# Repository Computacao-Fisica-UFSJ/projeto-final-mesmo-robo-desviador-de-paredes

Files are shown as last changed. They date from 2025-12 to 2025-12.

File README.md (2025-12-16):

# Projeto Hidroponia semi-autônomo

##### Contextualização do projeto, indicando suas aplicações e/ou motivação:

 	O intuito principal do projeto busca auxiliar cultivos de plantas no estilo hidropônico. A hidroponia é um estilo de plantação feita com as raízes da planta submersas em água nutrificada, o que o diferencia bastante do cultivo comum que geralmente requer solo geralmente fértil pra nutrição da planta pela raiz.

 	Nesse contexto, a arquitetura de hardware do projeto utiliza um microcontrolador Arduino Uno R3 como unidade central de processamento, responsável por gerenciar todas as leituras de sensores e as atuações automáticas do sistema.

Para a gestão da iluminação, o sistema emprega um sensor fotossensível LDR (Light Dependent Resistor) que monitora a incidência de luz em tempo real. Com base nesses dados, o Arduino aciona um micro servo motor acoplado mecanicamente ao eixo de um Dimmer de 2000W. Esta abordagem mecânica para o controle da intensidade da lâmpada foi adotada estrategicamente para garantir o isolamento entre o circuito de baixa tensão do microcontrolador e a alta tensão da rede elétrica, proporcionando maior segurança ao sistema enquanto assegura que a planta receba a iluminação adequada.

A aquisição de dados ambientais é realizada por sensores de alta precisão. Para a atmosfera do cultivo, utiliza-se um sensor DHT22, responsável por medir simultaneamente a temperatura e a umidade relativa do ar.

Já para o monitoramento da solução nutritiva, o projeto integra um sensor DS18B20, uma sonda digital impermeável ideal para medição submersa da temperatura da água.

Esses dados têm caráter informativo e são exibidos em uma interface homem-máquina composta por um display LCD 16x2, permitindo o acompanhamento instantâneo das condições vitais do cultivo.

Por fim, a estabilidade da nutrição é mantida por um sistema de reposição hídrica. Um sensor de nível monitora o reservatório e, ao detectar que o volume está abaixo do limiar predefinido, aciona uma bomba de água. Essa automação reabastece o sistema até que o nível se estabilize, evitando a exposição das raízes ou alterações drásticas na concentração de nutrientes.

##### Lista de materiais:

-Arduino Uno R3

-DS18B20(sensor de temperatura da água)

-fotoresistor LDR

-Micro Servo Motor 9g Sg90

-DHT22(sensor de temperatura e umidade)

-dimmer\_2000W(potenciomento da lâmpada fluorescente)

-lâmpada fluorescente

-FD10(sensor de nível de água)

AM2302-Sensor

DallasTemperature

ESP32_Thermistor

OneWire

Servo

GROVE - LCD RGB blacklight

DHT sensor library

##### Problemas encontrados no processo de montagem:

-Altas voltagem: para implementarmos a lâmpada fluorescente em nosso projeto temos o desafio de lidar com componenetes de alta voltagem (110 a 220V) o que pode causar eletrocutamento leve/moderado ao manusear componentes energizados sem o devido isolamento ou cuidado.

-O github não suporta armazenar as bibliotecas implementadas nos projetos devido ao grande número de arquivos(ele não carrega mais de 100 arquivos[pelo menos na interface de arrastar com o mouse no site, não]) o que tornou inviável salvar de forma segura as bibliotecas necessárias para o funcionamento do projeto. A alternativa que pensamos foi apenas salvar o nome das bibliotecas necessárias e, em caso de perda dessas bibliotecas de alguma forma, reinstalar uma por uma parar retomar os trabalhos.

-Tivemos muitos problemas para fazer o sensor de temperatura da água funcionar, pois não estávamos conseguindo configurar da forma correta. Devido a isso, tivemos que trocar o modelo e, após a troca, conseguimos resolver esse problema.

-Tivemos dificuldades para fazer o servo se mover na angulação correta. Além disso, foi necessário desenvolver um apoio para que o servo conseguisse aumentar e diminuir a intensidade da luz do dimmer, garantindo também a fixação adequada entre ambos.

-Outra dificuldade foi para fazer o servo funcionar junto com os outros sensores e atuadores, pois o 5V do Arduino não estava fornecendo energia suficiente para todos os componentes. Por isso, foi necessário utilizar o 5V do protoboard para garantir o funcionamento correto do sistema.

##### Diagrama da montagem:

##### Foto e vídeo do projeto:

##### Bibliotecas utilizadas:

##### 

##### Relatórios Diário

###### 

###### Dia 18/11
Querido diário, hoje buscamos pelos hardwares necessários para nosso projeto de medição de luminosidade, temperatura do ar e água, umidade, nível de água e regulador de luz e nível de água!

###### Dia 25/11
Querido diário, hoje eu e Lara criamos o código pro sensor de luminosidade, mais conhecido como LDR e pro sensor de temperatura e umidade do ar, menos conhecido como AOSONG AM2302. Também montamos ele no protoboard e depois no Arduíno, foi possível assistir a leitura tanto do nível de luminosidade do ambiente quanto o de umidade e temperatura

###### Dia 26/11
Querido diário, Lara está quebrando a cabeça pra saber como conectar o sensor de temperatura da água uma vez que ele tem uma entrada deveras estranha, ela conseguiu conectar as entradas de forma correta para lermos pelo Arduíno, eu compilei o código mas os testes foram meios decepcionantes, a temperatura da água que na teoria era pra ser ambiente teve leituras de valores menores que a água supostamente gelada, exemplo: quente:20 graus, gelada 33 graus. Enquanto eu tentava consertar de alguma forma esse empecilho, Lara achou sobre a montagem do nivelador de água mas saiu correndo com pressa pra não perder a carona e não iniciou a montar, e eu devo deixar pra tentar corrigir essa leitura depois também.

###### Dia 02/12
Querido diário, hoje ficamos por conta de fazer a prova de arduíno.

###### Dia 03/12
Querido dário, hoje implementamos separadamente os sensores de nível de água, o micro servo, o sensor de temperatura da água e o potenciômetro para controlar a intensidade da lâmpada. Inicialmente, tivemos problemas com o sensor de temperatura, que era um NTC 10k MF58, e não conseguimos fazê-lo funcionar corretamente, então resolvemos substituí-lo por um DS18B20. Após a troca, o sensor passou a funcionar da forma correta.

###### Dia 08/12
Querido diário, hoje conseguimos trocar o servo para que ele funcionasse por angulação, achamos um objeto 3d que grudamos nele para ele conseguir rodar o potenciometro do dimmer. Conseguimos também fazer o código base com todos os sensores funcionando. Além disso, conseguimos fazer o display começar a funcionar, porém com alguns problemas.

###### Dia 09/12
Querido diário, hoje conseguimos finalizar o código e apresentamos para a Milene. Conseguimos fazer a lógica do servo funcionar e também o relé da bomba funcionar. Colocamos o protótipo em uma caixa, posicionando a luz em um local adequado, próximo ao LDR, para que a lógica funcionasse corretamente. Além disso, posicionamos o dimmer e o servo de forma que o servo conseguisse girar o potenciômetro e, por último, arrumamos o display para mostrar os valores das variáveis obtidas por alguns sensores. Além disso, houve um grande avanço no README, com toda a contextualização feita, a listagem de componentes com suas respectivas imagens e um avanço no projeto em Fritzing.

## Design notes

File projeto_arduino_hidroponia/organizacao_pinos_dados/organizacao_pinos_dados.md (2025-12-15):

###Organização pinos de dados

A0->sensor de luminosidade(ldr)

A1->sensor de temperatura da agua

A2->sensor de nivel de agua

7U->sensor de umidade e temperatura do ar

6~->micro servo

SDA-display

SCL-display

2D-relé

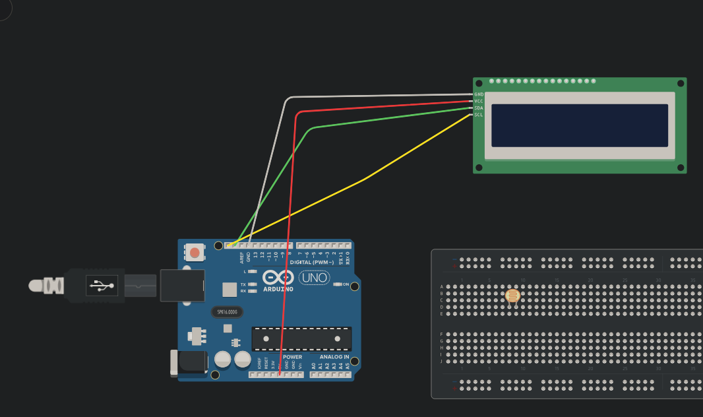
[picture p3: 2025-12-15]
projeto_arduino_hidroponia/image.png

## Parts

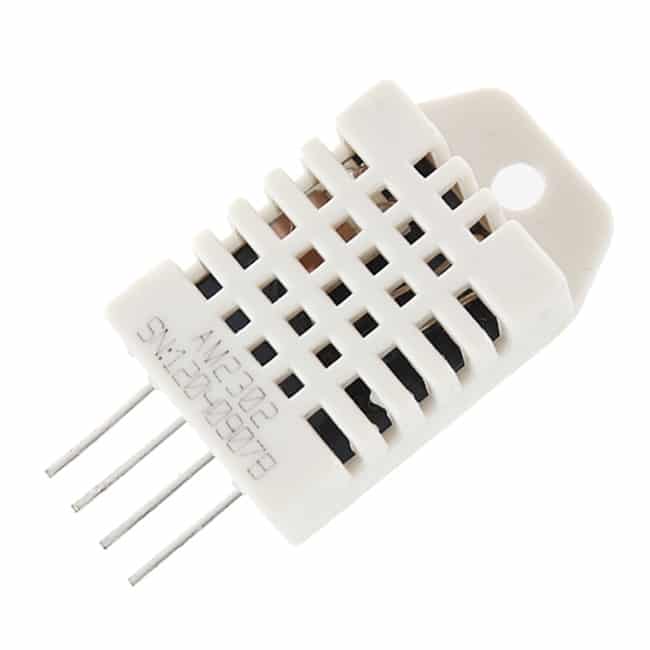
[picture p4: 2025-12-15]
imagem_componentes/DHT22(sensor_umidade_temperatura).jpg

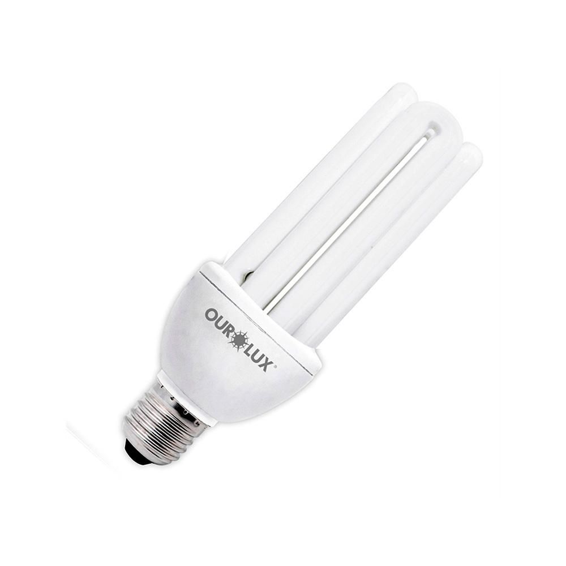
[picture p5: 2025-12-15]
imagem_componentes/lampada-eletronica-30w-x-220v-am-2700k-ourolux_1_1000.jpg

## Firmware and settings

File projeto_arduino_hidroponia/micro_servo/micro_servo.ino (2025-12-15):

// Programa: Controlando um servo motor com Arduino (servo motor arduino code) 

#include <Servo.h> // Inclui a biblioteca Servo para controlar servos

Servo meuServo; // Cria um objeto Servo para controlar o servo motor
int pos; // Declara uma variável para controlar a posição do servo motor 

void setup() {
    meuServo.attach(6); // Associa o servo motor ao pino digital 6 do Arduino
    meuServo.write(0); // Define a posição inicial do servo motor para 0 graus
}

void loop() {
    // Movimento do servo de 0 a 90 graus
    for (pos = 0; pos < 90; pos++) {
        meuServo.write(pos); // Define a posição atual do servo
        delay(15); // Aguarda 15 milissegundos antes de mover para a próxima posição
    }
    delay(1000); // Aguarda 1 segundo antes de iniciar o próximo movimento

    // Movimento do servo de 90 a 0 graus
    for (pos = 90; pos >= 0; pos--) {
        meuServo.write(pos); // Define a posição atual do servo
        delay(15); // Aguarda 15 milissegundos antes de mover para a próxima posição
    }
    delay(1000); // Aguarda 1 segundo antes de iniciar o próximo ciclo
}

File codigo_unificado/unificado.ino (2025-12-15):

#include <Wire.h> 
#include <rgb_lcd.h>
#include <Servo.h>
#include <DHT.h>
#include <OneWire.h>
#include <DallasTemperature.h>

#define DHTTYPE DHT22

// Pinos 
#define pinoRele 2
#define pinoLDR A0
#define pinoNivelAgua A2
#define pinoDHT 7
#define pinoServo 6
#define pinoTempAgua 8

//Constantes de tempo
#define intervaloTempo 2000
#define intervaloServo 2000
#define intervaloRele 4000

// Variáveis
int valorLDR = 0;
int valorNivel = 0;
float valorTempAr = 0.0;
float valorUmidade = 0.0;
float valorTempAgua = 0.0;
int intensidadeLuz = 0;
int angulo = 0;
int porcentagemNivel = 0;
int estadoRele = 0;

// variáveis de tempo
unsigned long tempoAtual;
unsigned long tempoAnterior = 0;
unsigned long tempoAnteriorServo = 0;
unsigned long tempoAnteriorRele = 0;

//Objetos
Servo servo;
rgb_lcd LCD;
DHT dht(pinoDHT, DHTTYPE);
OneWire sensorTemp(pinoTempAgua);
DallasTemperature sensors(&sensorTemp);

//Funções
void controleServo(){
// Aguarda 4 segundo antes de iniciar o próximo ciclo

  
  if(intensidadeLuz < 65 && angulo < 90){
    if(tempoAtual - tempoAnteriorServo >= intervaloServo){
      tempoAnteriorServo = tempoAtual;
      angulo+=2;
      servo.write(angulo);
    }
  }else if(intensidadeLuz > 85 && angulo > 0){
    if(tempoAtual - tempoAnteriorServo >= intervaloServo){
      tempoAnteriorServo = tempoAtual;
      angulo-=2;
      servo.write(angulo);
    }
  }
}

void setup()
{
  Serial.begin(9600);

  //Seta os pinos
  pinMode(pinoRele,OUTPUT);
  pinMode(pinoLDR, INPUT);
  pinMode(pinoNivelAgua, INPUT);
  dht.begin();
  sensors.begin();
  LCD.begin(16, 2);
  LCD.setRGB(255, 255, 255);
  servo.attach(pinoServo, 500, 2500);

  // --- CONFIGURAÇÃO INICIAL DA TELA (Labels Fixos) ---
  // Limpamos a tela uma vez
  LCD.clear();
  
  // Linha 0: Temperatura
  LCD.setCursor(0, 0); 
  LCD.print("T:     U: "); // Escreve o rótulo fixo
  
  // Linha 1: Luz
  LCD.setCursor(0, 1);
  LCD.print("N:     TA: ");     // Escreve o rótulo fixo
  servo.write(0);
}

void loop()
{  
  tempoAtual = millis();
  
  //Calculo do tempo com millis
  if(tempoAtual - tempoAnterior >= intervaloTempo){
    tempoAnterior = tempoAtual;

    sensors.requestTemperatures();
    
    // 1. Leitura dos Sensores
    valorTempAr = dht.readTemperature();
    valorNivel = analogRead(pinoNivelAgua);
    valorUmidade = dht.readHumidity();
    valorTempAgua = sensors.getTempCByIndex(0);
    valorLDR = analogRead(pinoLDR);
    intensidadeLuz = map(valorLDR, 0, 1023, 1, 100);
    porcentagemNivel = map(valorNivel, 0, 650, 0, 100);
  
    // 2. Atualização no LCD (Sem Scroll)

    // A função isnan() verifica se o valor "Não é um Número"
    if (isnan(valorTempAr) || isnan(valorUmidade)) {
      Serial.println("FALHA AO LER O DHT!");
      LCD.setRGB(255, 0, 0); // Tela Vermelha
      LCD.setCursor(2, 0);
      LCD.print("Erro");
      LCD.setCursor(8, 0);
      LCD.print("Sensor");
      
    }else{
      
      // Atualiza Temperatura (Linha 0, Coluna 2 - logo após "T: ")
      LCD.setCursor(2, 0);
      LCD.print((int)valorTempAr); 
      LCD.print("C "); // O espaço extra limpa sujeira se o número diminuir (de 100 pra 99)
  
      //Atualiza umidade (Linha 0, Coluna 8 - logo após "U: ")
      LCD.setCursor(9, 0);
      LCD.print((int)valorUmidade);
      LCD.print("% "); // Espaço extra para limpeza
    
      // Atualiza Luz (Linha 1, Coluna 2 - logo após "L: ")
      LCD.setCursor(2, 1);
      LCD.print(porcentagemNivel);
      LCD.print("% "); // Espaço extra para limpeza

      //Atualiza a temperatura da agua (Linha 1, Coluna 9 - logo após "TA: ")
      LCD.setCursor(10, 1);
      LCD.print((int)valorTempAgua);
      LCD.print("C "); // Espaço extra para l
      
  
      //Muda a cor do display caso as variáveis de risco estejam no limite
      if(valorTempAr > 40.0 || valorUmidade < 40.0 || valorTempAgua > 30 || porcentagemNivel < 20){
       LCD.setRGB(255, 0, 0);
      }else{
        LCD.setRGB(255, 255, 255);
      }
      
    }

  
    // 3. Serial e Servo
    Serial.print("Temp: ");
    Serial.print(valorTempAr);
    Serial.print(" | Umidade: ");
    Serial.println(valorUmidade);
    Serial.print("Nivel de Agua: ");
    Serial.println(valorNivel);
    Serial.print("Porcentagem:");
    Serial.println(porcentagemNivel);
    Serial.print(" | Temperatura Agua: ");
    Serial.println(valorTempAgua);
    Serial.print(" | luz: ");
    Serial.print(intensidadeLuz);
    Serial.print(" | Angulo: ");
    Serial.println(angulo);
  }
  //codigo para ligar e desligar o relé
  if(tempoAtual - tempoAnteriorRele >= intervaloRele){       
    tempoAnteriorRele = tempoAtual;

    if (estadoRele == 0){
      digitalWrite(pinoRele,HIGH);
      estadoRele = 1;
    }
    else if(estadoRele == 1){
      digitalWrite(pinoRele,LOW);
      estadoRele = 0;
    }
  }
  controleServo();
}

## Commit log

2025-11-25 codigo pro sensor de humidade e temperatura
    mede tempo e humi no monitor serial
2025-12-03 nivel_agua e microservo implementados, criação de organizaçao de pinos e correção no umidade e temperatura
